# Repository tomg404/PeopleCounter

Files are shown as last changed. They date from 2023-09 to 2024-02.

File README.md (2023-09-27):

# People sensor / door sensor project
I needed a sensor which detects if someone or something entered or left a room. as i didn't find anything online i decided
to hack together my own little sensor. 

In my first try I utilised two `hc-sr04` ultrasonic sensors, but i quickly realised that their accuracy is horrible.
Another problem was that using two sensors needs a huge timeout (30-60ms) between their distance measurements, otherwise
they  will interfere each other and the results are _unusable_. They work for applications where things move slow, but
for this project I needed more **speeeeed**.

So my second thought was that two light barriers would work best. But one light barrier needs two parts. A sender and a
receiver. So this is also not the best solution to my problem as I want to mount the sensor on a door frame and don't want 
cables running all over the door frame.

Then I learned about time-of-flight (tof) sensors. They measure the distance to an object by shooting an infrared light
ray against the object and wait until the light is reflected back into the receiver. So they can essentially act like
a light barrier. I bought two `vl53l0x` tof sensors for ~8eur, tested them and got to the conclusion that they are 
perfect for this application. Not only do they **not** interfere with each other when relatively close together, these
sensors can also be probed extremely fast. In the fastest mode (continuous back-to-back ranging mode) the sensor has a
measurement ready for use every 20ms. Additionally, I can take measurements from both sensors at the same time. This
adds up to 50 measurements per second, per sensor. This is plenty enough to track a person walking through a door.

# Sample schematic
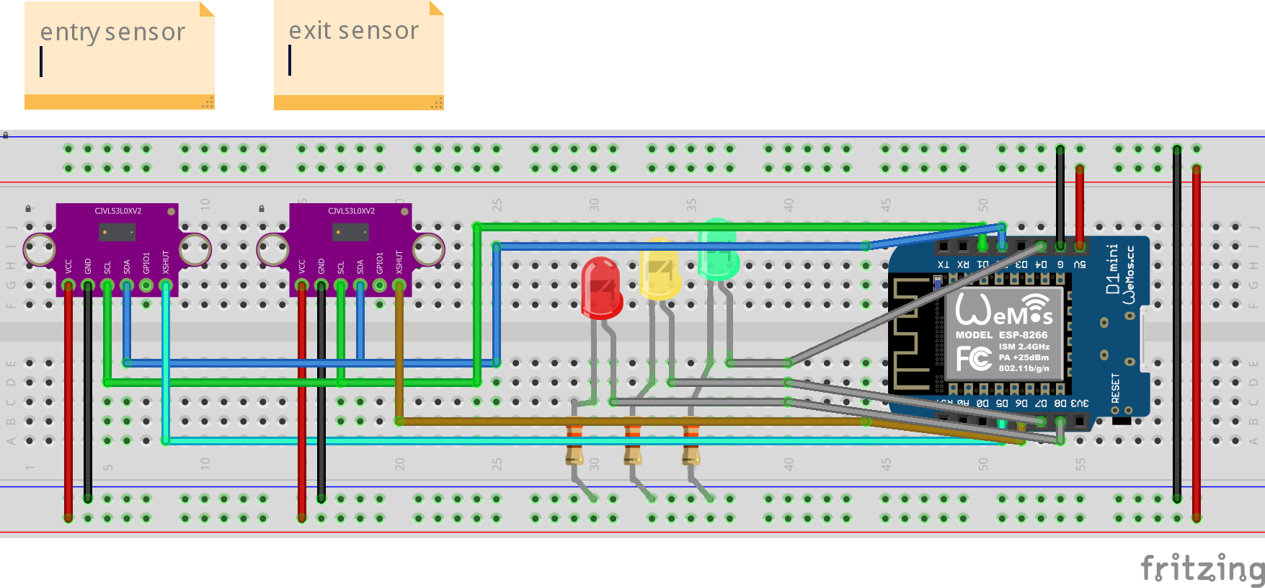
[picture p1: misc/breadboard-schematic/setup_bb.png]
sample breadboard setup


# Case


# todo
- [ ] make project run from batteries
- [ ] use deep-sleep mode as tof sensors don't need to probe constantly (wakeup from small ir sensor?)
- [ ] wifi stuff

# Useful resources
* **esp8266**
  * exception decoder: https://www.dzombak.com/blog/2021/10/ESP8266-PlatformIO-Serial-Console-Monitoring-with-Exception-Decoding.html
  * exception codes/causes: https://www.espressif.com/sites/default/files/documentation/esp8266_reset_causes_and_common_fatal_exception_causes_en.pdf
  * pinout: https://cdn.shopify.com/s/files/1/1509/1638/files/D1_Mini_Pinout_Diagram.pdf?5603303439559815202
  * board versions: https://docs.wemos.cc/en/latest/d1/index.html

* **hc-sr04 ultrasonic sensor**
  * explanation of sensor: https://randomnerdtutorials.com/complete-guide-for-ultrasonic-sensor-hc-sr04/
  * data sheet: https://docs.google.com/document/d/1Y-yZnNhMYy7rwhAgyL_pfa39RsB-x2qR4vP8saG73rE/edit?pli=1
  * NewPing library: https://bitbucket.org/teckel12/arduino-new-ping/wiki
  * multiple ultrasonic sensors: https://bitbucket.org/teckel12/arduino-new-ping/wiki/Help%20with%2015%20Sensors%20Example%20Sketch

* **vl53l0x laser ranging sensor**
  * good explanation of sensor: https://wolles-elektronikkiste.de/vl53l0x-und-vl53l1x-tof-abstandssensoren
  * data sheet: https://www.st.com/resource/en/datasheet/vl53l0x.pdf

* **misc**
  * interrupts/timers: https://randomnerdtutorials.com/interrupts-timers-esp8266-arduino-ide-nodemcu/
  * finite state design pattern: https://www.aleksandrhovhannisyan.com/blog/implementing-a-finite-state-machine-in-cpp/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
  * fsm in c++: https://www.cppstories.com/2023/finite-state-machines-variant-cpp/

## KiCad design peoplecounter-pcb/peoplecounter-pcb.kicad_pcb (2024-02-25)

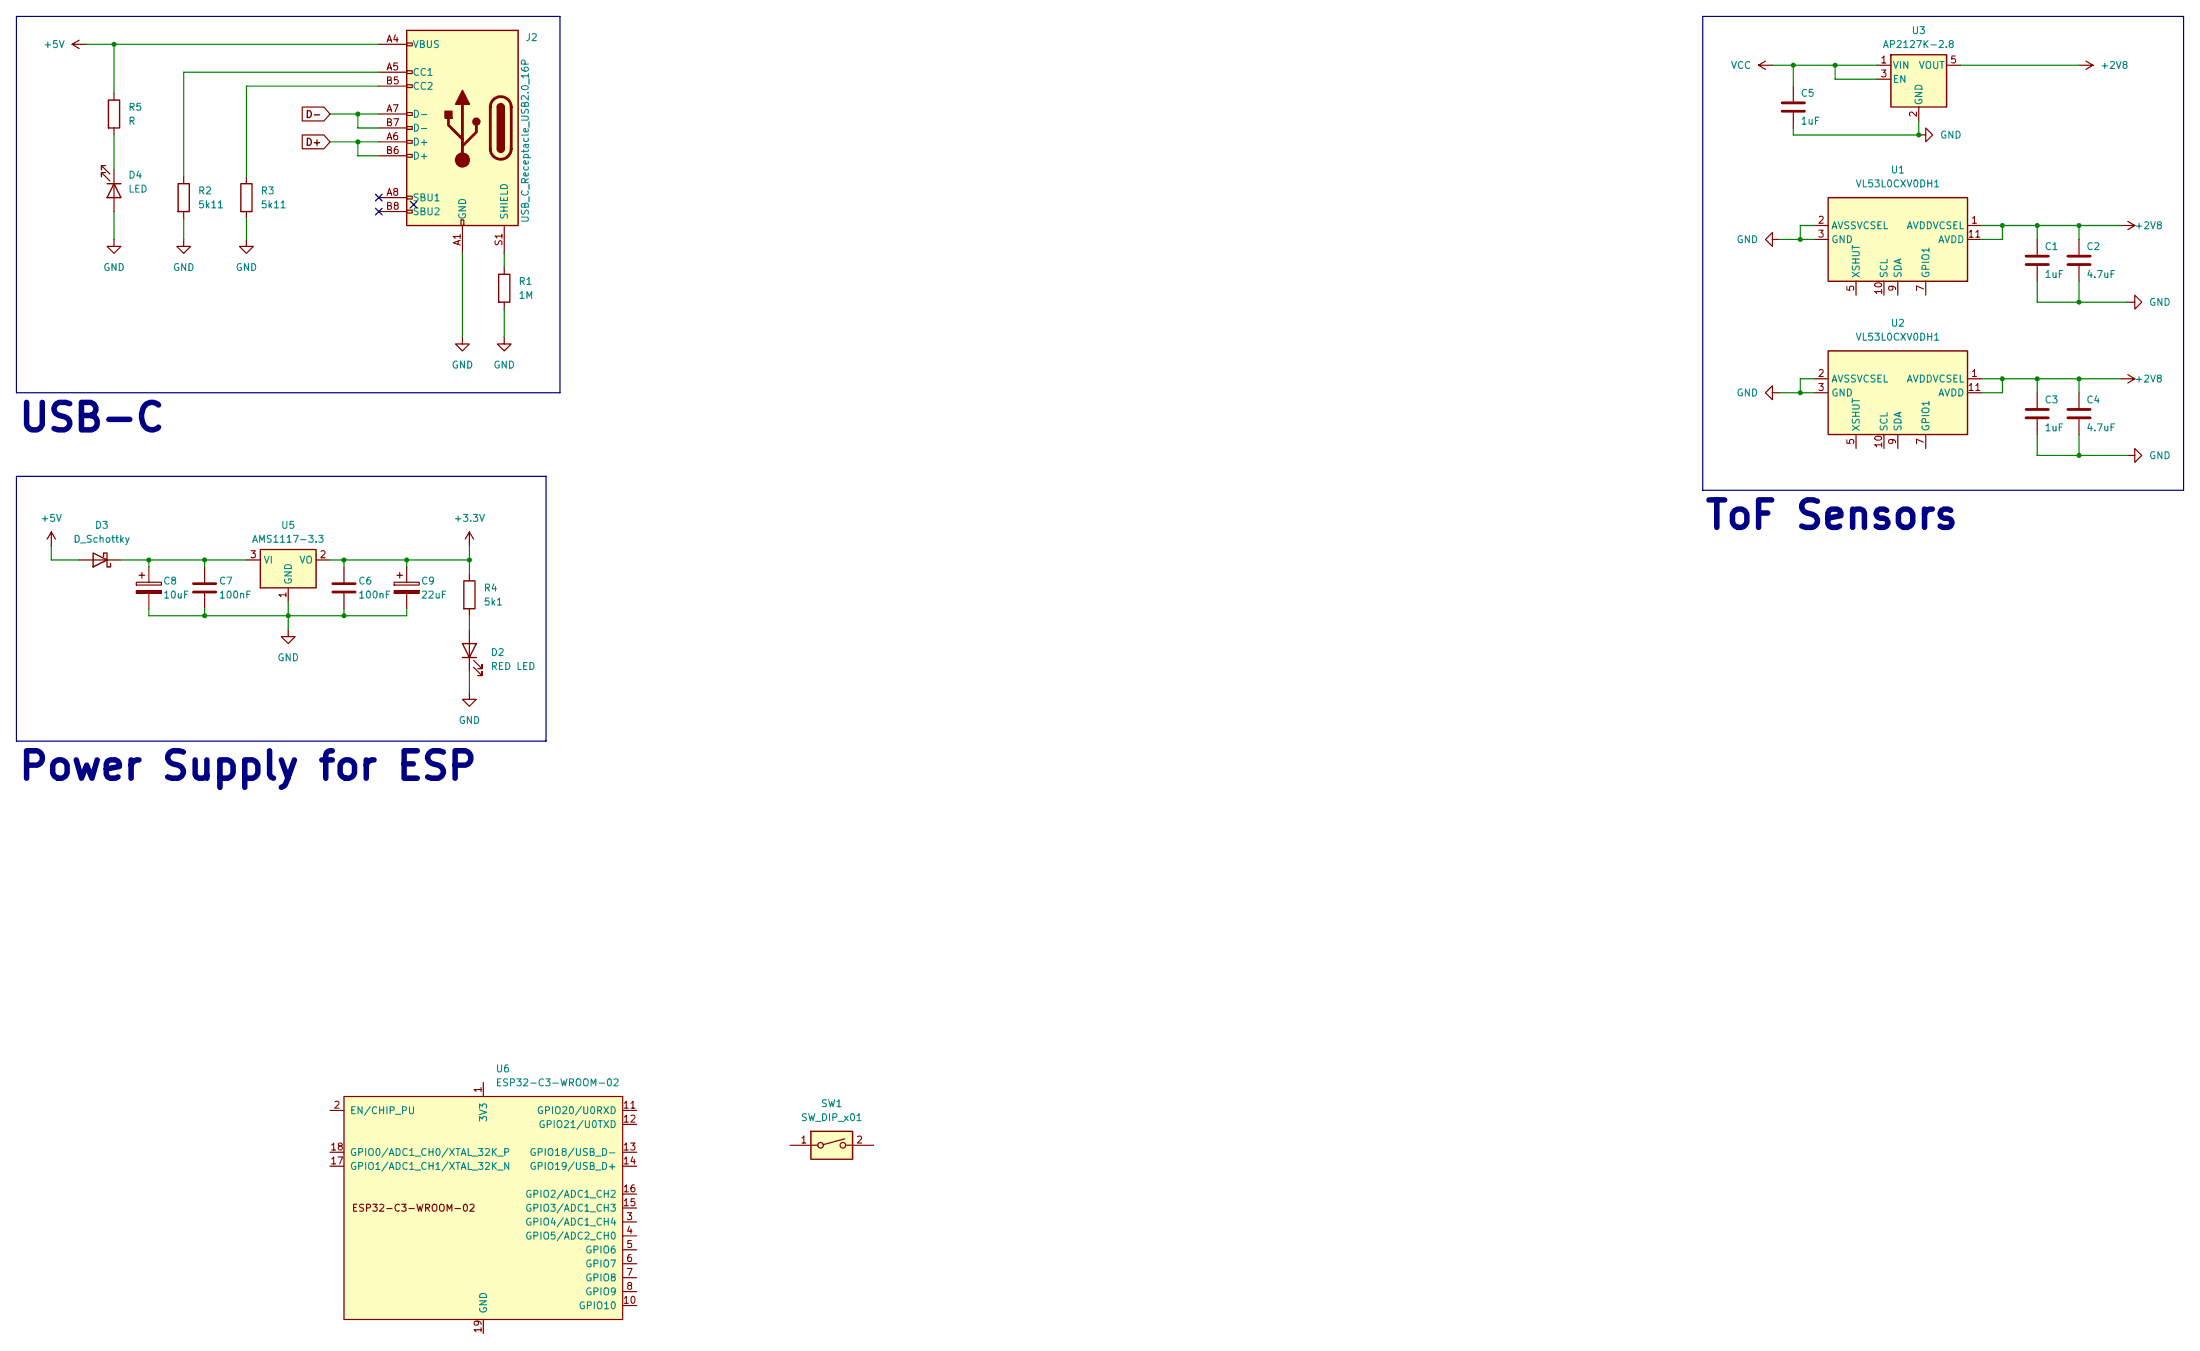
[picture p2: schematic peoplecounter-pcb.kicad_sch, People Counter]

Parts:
C1, C3, C5: 1uF; C_1206_3216Metric_Pad1.33x1.80mm_HandSolder
C2, C4: 4.7uF; C_1206_3216Metric_Pad1.33x1.80mm_HandSolder
C6, C7: 100nF; C_1206_3216Metric_Pad1.33x1.80mm_HandSolder
C8: 10uF; CP_Elec_5x5.3
C9: 22uF; CP_Elec_5x5.3
D2: RED LED; LED_1206_3216Metric_Pad1.42x1.75mm_HandSolder
D3: D_Schottky; D_1206_3216Metric_Pad1.42x1.75mm_HandSolder
D4: LED; LED_1206_3216Metric_Pad1.42x1.75mm_HandSolder
J2: USB_C_Receptacle_USB2.0_16P; USB_C_Receptacle_Amphenol_12401610E4-2A
R1: 1M; LED_1206_3216Metric_Pad1.42x1.75mm_HandSolder
R2, R3: 5k11; R_1206_3216Metric_Pad1.30x1.75mm_HandSolder
R4: 5k1; R_1206_3216Metric_Pad1.30x1.75mm_HandSolder
R5: R; R_1206_3216Metric_Pad1.30x1.75mm_HandSolder
SW1: SW_DIP_x01; SW_DIP_SPSTx01_Slide_Omron_A6S-110x_W8.9mm_P2.54mm
U1, U2: VL53L0CXV0DH1; ST_VL53L1x
U3: AP2127K-2.8; SOT-23-5
U5: AMS1117-3.3; SOT-223-3_TabPin2
U6: ESP32-C3-WROOM-02

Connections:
+2V8: C1.1, C2.1, C3.1, C4.1, U1.1 (AVDDVCSEL), U1.11 (AVDD), U2.1 (AVDDVCSEL), U2.11 (AVDD), U3.5 (VOUT)
+3.3V: C6.1, C9.1, R4.1, U5.2 (VO)
+5V: D3.2 (A), J2.A4 (VBUS), J2.A9 (VBUS), J2.B4 (VBUS), J2.B9 (VBUS), R5.1
D+: J2.A6 (D+), J2.B6 (D+)
D-: J2.A7 (D-), J2.B7 (D-)
GND: C1.2, C2.2, C3.2, C4.2, C5.2, C6.2, C7.2, C8.2, C9.2, D2.1 (K), D4.2 (A), J2.A1 (GND), J2.A12 (GND), J2.B1 (GND), J2.B12 (GND), R1.2, R2.2, R3.2, U1.2 (AVSSVCSEL), U1.3 (GND), U1.4 (GND), U1.6 (GND), U1.12 (GND), U2.2 (AVSSVCSEL), U2.3 (GND), U2.4 (GND), U2.6 (GND), U2.12 (GND), U3.2 (GND), U5.1 (GND)
unnamed: D2.2 (A), R4.2
unnamed: C7.1, C8.1, D3.1 (K), U5.3 (VI)
unnamed: D4.1 (K), R5.2
unnamed: J2.A5 (CC1), R2.1
unnamed: J2.B5 (CC2), R3.1
unnamed: J2.S1 (SHIELD), R1.1
unnamed: U6.9 (GND), U6.19 (GND)
VCC: C5.1, U3.1 (VIN), U3.3 (EN)

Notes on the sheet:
ToF Sensors
USB-C
Power Supply for ESP

Board: 2 copper layers, 25 parts (0 on the bottom side), 14 nets, no tracks yet.

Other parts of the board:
D1: LED_RBGA; LED_Kingbright_AAA3528ESGCT

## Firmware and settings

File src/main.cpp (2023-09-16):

#include <Wire.h>
#include <Arduino.h>
#include <memory>

#include "PeopleSensor.h"

/* uncomment to switch entry sensor with exit sensor */
//#define FLIP_ORIENTATION

/* uncomment to enable some debug messages */
#define DEBUG

/* uncomment to see if the sensors are working */
//#define TEST

/* uncomment to disable output code like led's */
//#define DONT_USE_OUTPUT

/* sensor settings */
constexpr uint32_t sensorTimeout{100}; // abort measurement after x ms
constexpr uint32_t measurementTimingBudget{20000}; // 20ms (default is 33ms)
constexpr uint8_t entrySensorAddress{0x30};
constexpr uint8_t exitSensorAddress{0x31};

/* pin definitions */
constexpr uint8_t entrySensorXshut{14}; // D5
constexpr uint8_t exitSensorXshut{12}; // D6
constexpr uint8_t entrySensorGpio0{0}; // currently not defined
constexpr uint8_t exitSensorGpio0{0}; //

constexpr uint8_t enterLedPin{2}; // D4
constexpr uint8_t exitLedPin{13}; // D7
constexpr uint8_t errorLedPin{15}; // D8

std::shared_ptr<Output> out;
std::unique_ptr<PeopleSensor> ps;

void setup() {
    Serial.begin(115200); // initialize serial connection
    Wire.begin(); // initialize two-wire

    Serial.printf("\nStarting people counter...\n");

#ifndef FLIP_ORIENTATION
    ps = std::make_unique<PeopleSensor>(entrySensorXshut, exitSensorXshut, entrySensorGpio0, exitSensorGpio0,
                                        entrySensorAddress, exitSensorAddress, sensorTimeout,measurementTimingBudget);
#else
    ps = std::make_unique<PeopleSensor>(exitSensorXshut, entrySensorXshut, exitSensorGpio0, entrySensorGpio0,
                                        exitSensorAddress, entrySensorAddress, sensorTimeout,measurementTimingBudget);
#endif

#ifndef DONT_USE_OUTPUT
    out = std::make_shared<Output>(enterLedPin, exitLedPin, errorLedPin);
    ps->setOutput(out);
#endif

}

#ifndef TEST
void loop() {
    ps->update();
    #ifndef DONT_USE_OUTPUT
    out->update();
    #endif
}
#else
void loop() {
    Serial.printf("s1: %d, s2: %d\n",
                  ps->getEntrySensor().readRangeContinuousMillimeters(),
                  ps->getExitSensor().readRangeContinuousMillimeters());
}
#endif

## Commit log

2023-09-27 add experimental LED class
2024-02-24 add kicad project files
    [peoplecounter-pcb.kicad_pcb, peoplecounter-pcb.kicad_sch]
